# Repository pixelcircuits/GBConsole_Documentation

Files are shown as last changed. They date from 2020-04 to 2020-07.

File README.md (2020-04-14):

# GameBoy Console
The GameBoy Console is an emulator that plays physical GameBoy, GameBoy Color and GameBoy Advance cartridges on your TV! The goal of this project is to provide an inexpensive solution for revisiting beloved GameBoy games on the big screen and help preserve cartridge save data.

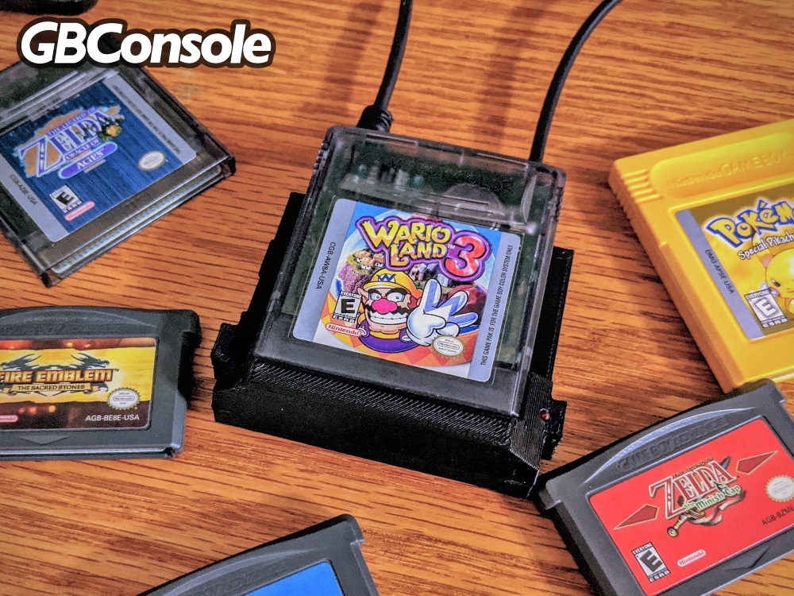
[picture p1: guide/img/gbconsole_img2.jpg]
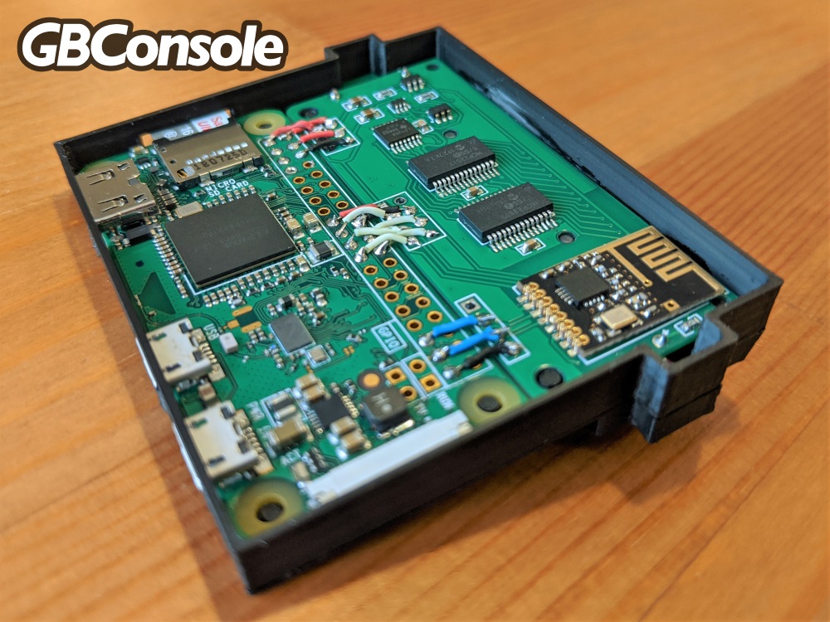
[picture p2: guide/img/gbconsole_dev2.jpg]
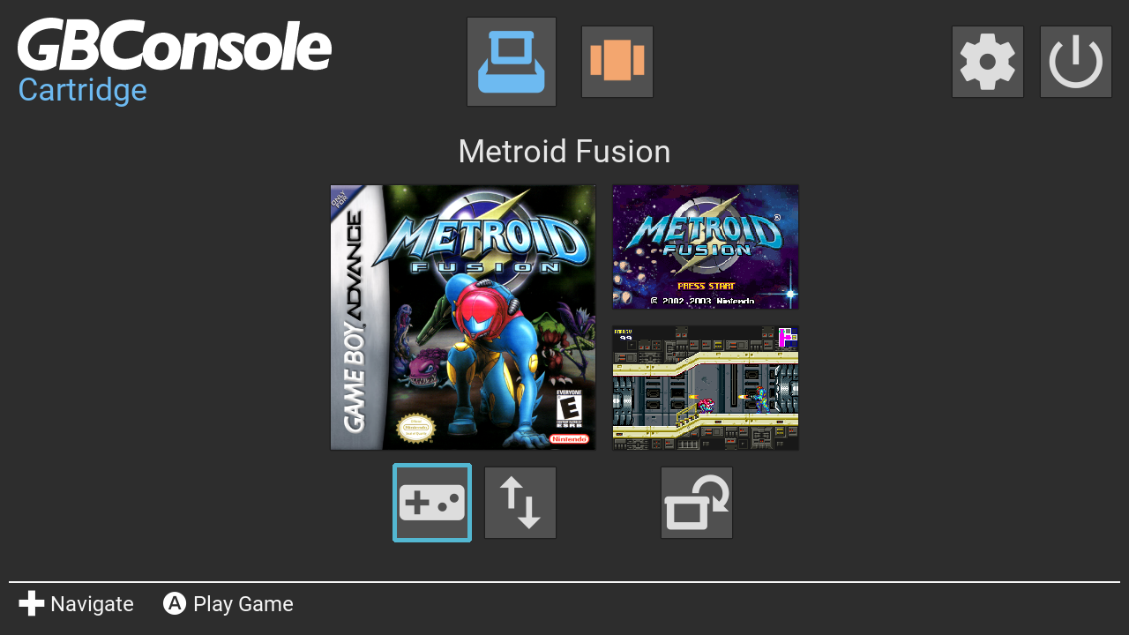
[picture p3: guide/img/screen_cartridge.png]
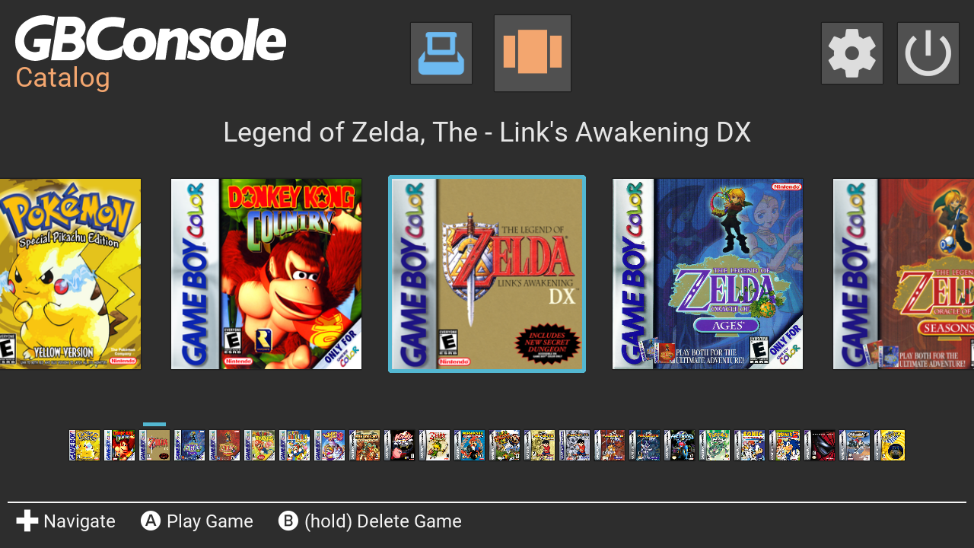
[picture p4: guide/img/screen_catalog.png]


## Documentation
Refer to the following links for more info on the assembly and features of the GameBoy Console.
* [Case Assembly](/case)
* [PCB Assembly](/pcb)
* [Software Setup](https://github.com/pixelcircuits/GBConsole)
* [User Guide](/guide)

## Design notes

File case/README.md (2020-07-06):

# GameBoy Console Case
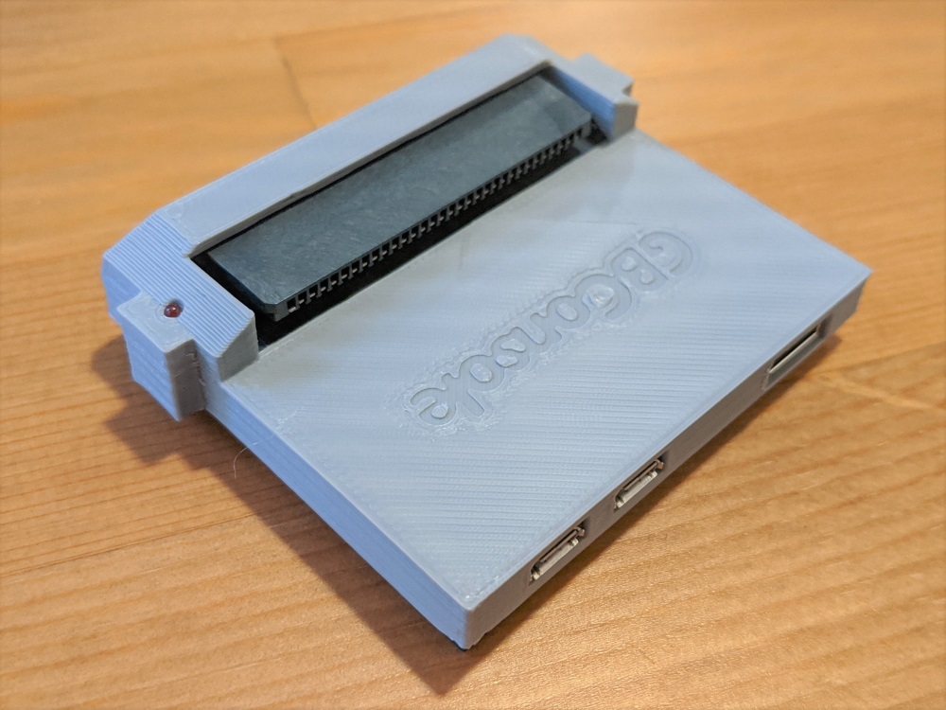
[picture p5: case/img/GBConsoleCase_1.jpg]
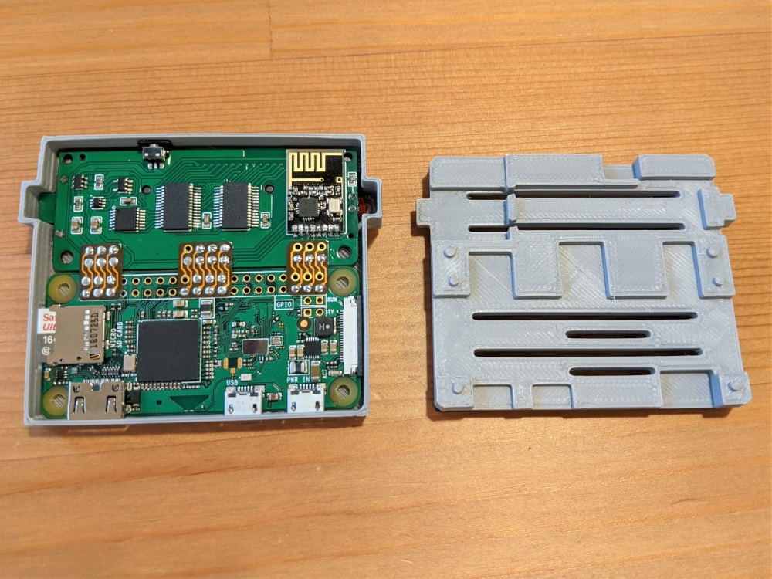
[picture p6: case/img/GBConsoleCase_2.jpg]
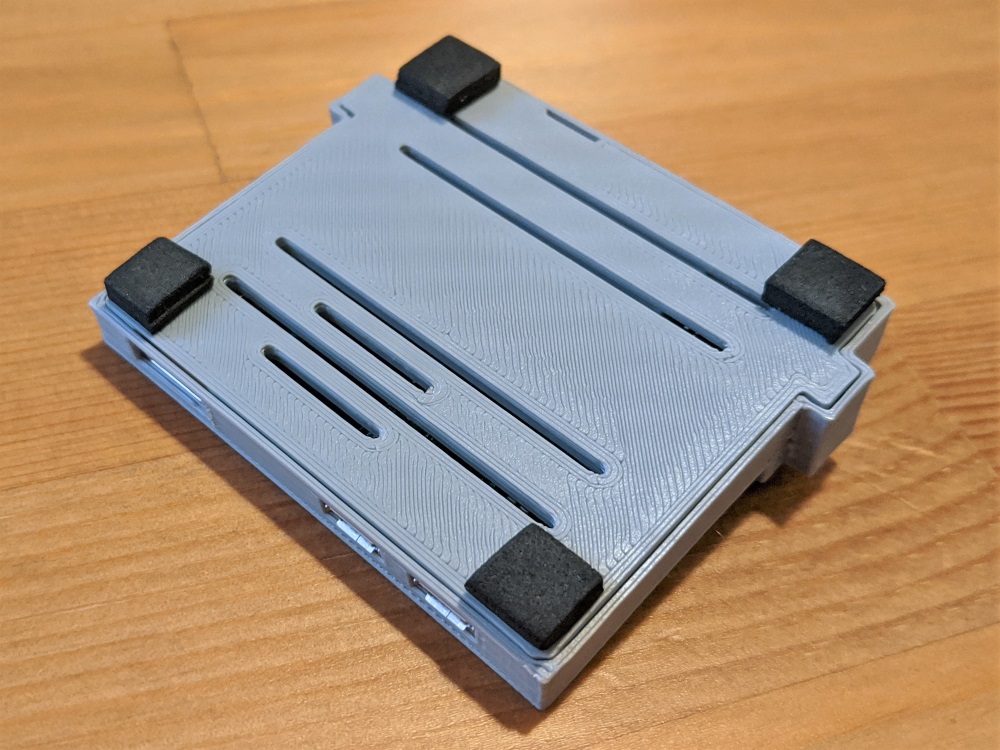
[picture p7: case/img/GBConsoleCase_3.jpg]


The GameBoy Console was designed to fit nicely into a 3D printed case. The case consists of two main parts (body and bottom).

## Case Body
The case body is split into two parts (top and bottom). These two pieces should friction fit together with all the circuitry placed inside. Rubber feet should be applied to the bottom four corners to elevate the case and allow airflow to carry away heat.
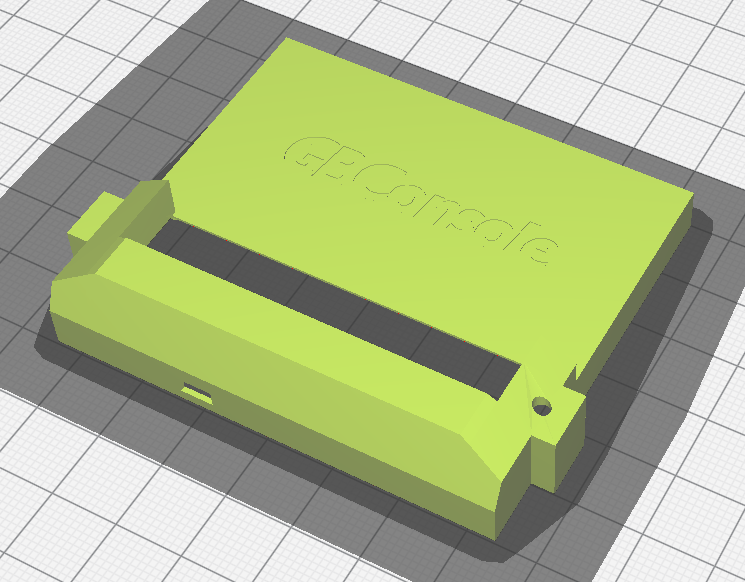
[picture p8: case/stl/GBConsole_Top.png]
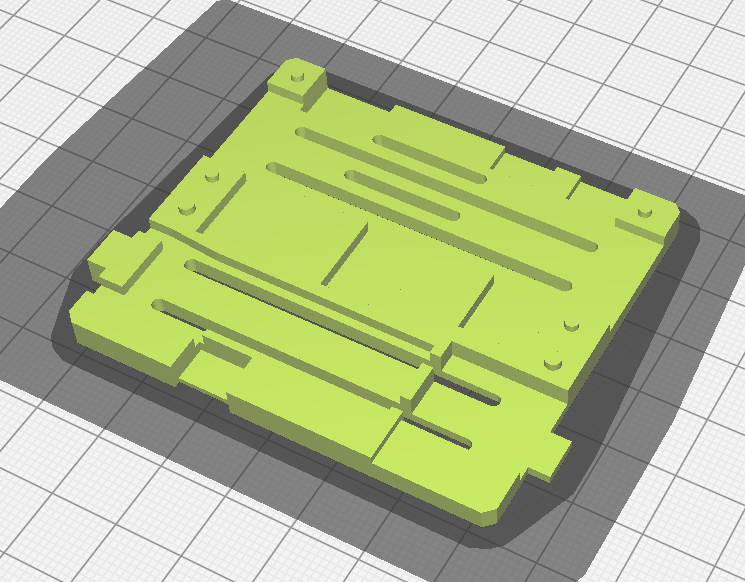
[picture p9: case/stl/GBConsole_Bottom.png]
|  |  |
| --- | --- |
| [GBConsole_Top.stl](stl/GBConsole_Top.stl) | [GBConsole_Bottom.stl](stl/GBConsole_Bottom.stl) |

## Case Button
Additionally, there is a small button cap to help trigger the tact switch through the front side of the case.
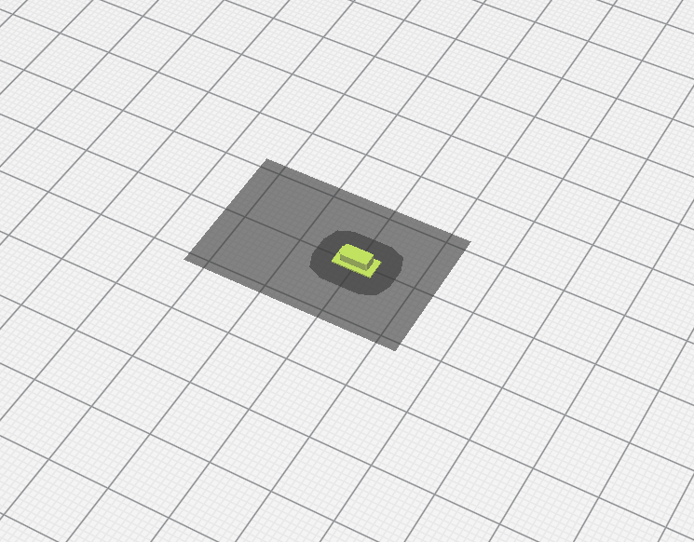
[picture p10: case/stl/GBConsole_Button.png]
|  |
| --- |
| [GBConsole_Button.stl](stl/GBConsole_Button.stl) |

## Assembly
To assemble the GameBoy Console case, fit the fully soldered circuitry into the top of the case by placing in the Raspberry Pi side first (make sure to remove the SD card). The case bottom should then fit and lock into place from the print lines. Refer to the photos if you need additional help.

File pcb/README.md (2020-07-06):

# GameBoy Console PCB
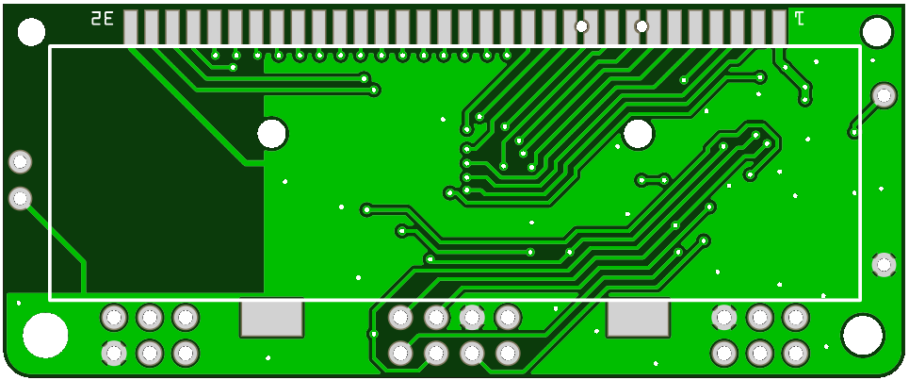
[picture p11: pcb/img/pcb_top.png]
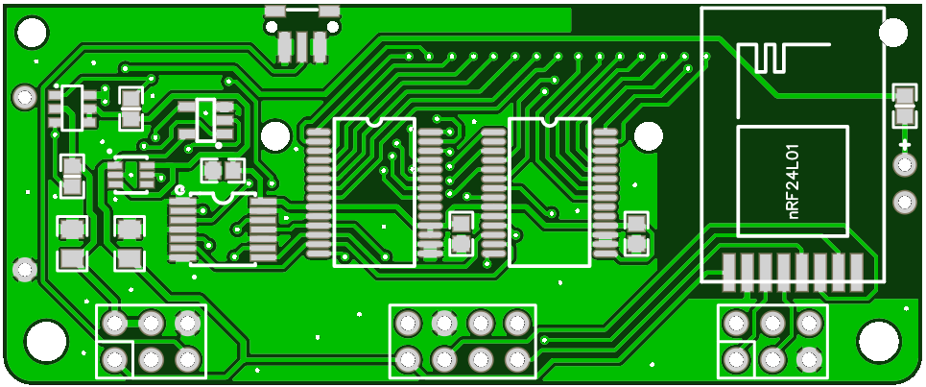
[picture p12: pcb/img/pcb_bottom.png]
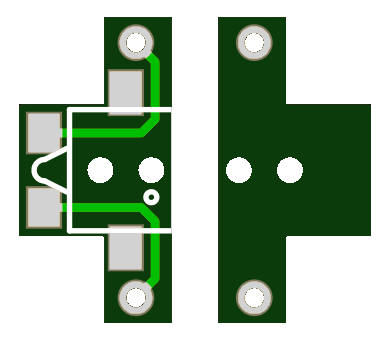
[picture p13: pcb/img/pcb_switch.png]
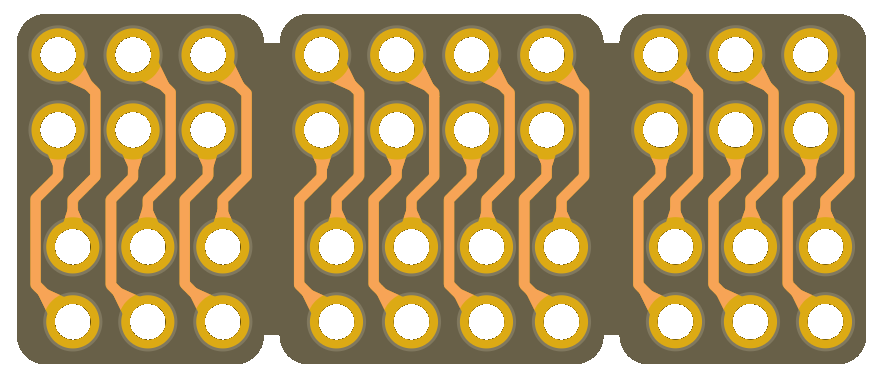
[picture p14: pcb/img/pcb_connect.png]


The GameBoy Console utilizes a custom PCB connected to the GPIO of a Raspberry Pi to help interface with GameBoy, GameBoy Color and GameBoy Advance cartridges. The PCB also includes space for an RF module to help connect to different wireless controllers. Along with the main board, there is a riser PCB for the detector swith and a flex PCB to help easy wire the main board to a Raspberry Pi.

## Schematic Overview
The circuitry consists primarily of two GPIO expander chips (MCP23S17T) to both reduce GPIO requirements and allow for easier logic shifting from 3.3 to 5 volts. There are two ICs (SN74LV1T125 and SN74LVC125A) which buffer the data signals coming from and to the Raspberry Pi. There are two additional ICs (LM66100 and DMP2240UDM) which help to switch the logic level and control power to the connected cartridge.
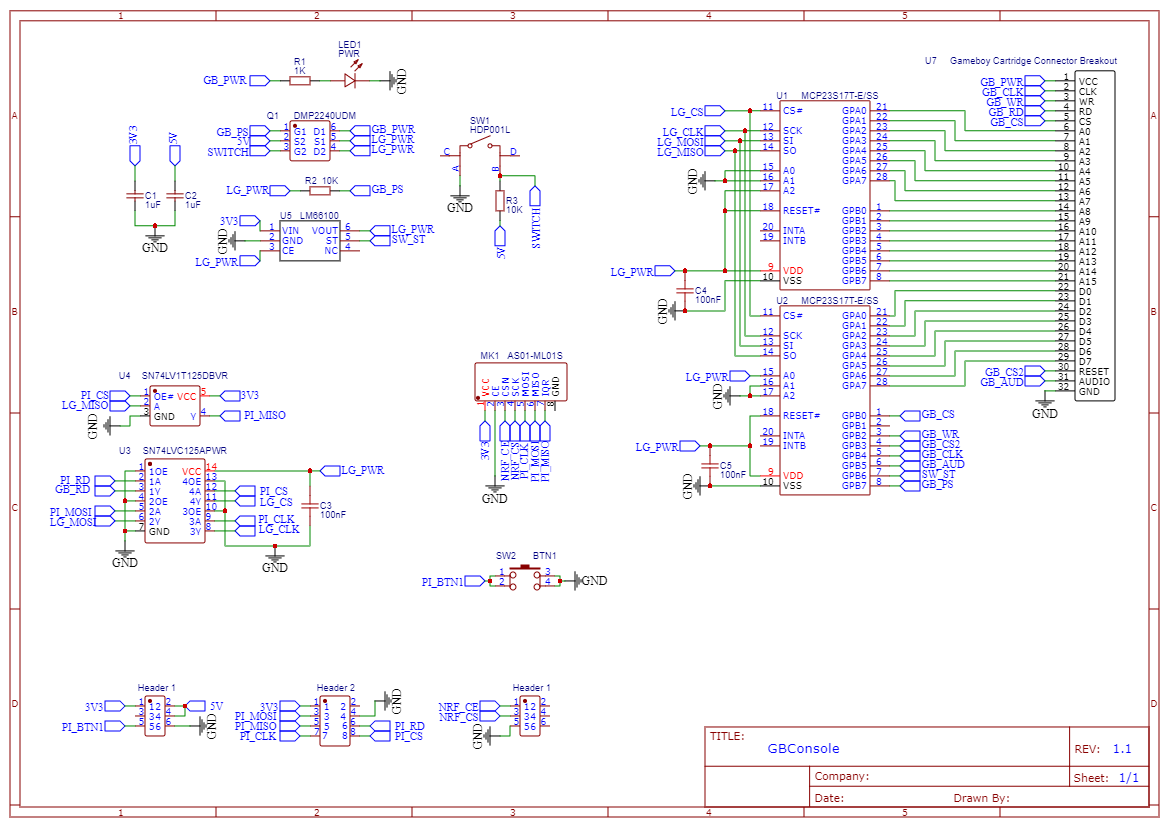
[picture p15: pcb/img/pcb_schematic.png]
Schematic


## Assembly
The gerber files for the main PCB (~1.4mm thickness) can be found [here](gerber/pcb_gerber.zip) and the gerber files for the detector switch PCB (~1mm thickness) can be found [here](gerber/pcb_switch_gerber.zip). Note that the detector switch is first soldered to its own PCB and then soldered to the main PCB. Additionally, a flex PCB for easier wiring can be found [here](gerber/pcb_connect_gerber.zip). Refer to the following diagram for how to assemble the PCB. 
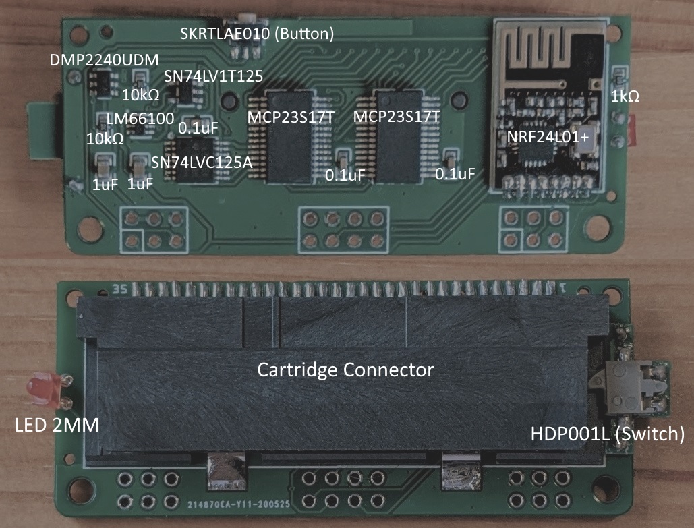
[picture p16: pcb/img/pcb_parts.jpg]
Assembly


## Parts
| Part | Footprint | Qty | Link |
| --- | --- | --- | --- |
| MCP23S17T | SSOP-28 | 2 | [mouser](https://www.mouser.com/ProductDetail/579-MCP23S17T-E-SS) |
| SN74LV1T125 | SOT-23-5 | 1 | [mouser](https://www.mouser.com/ProductDetail/595-74LV1T125DBVRG4) |
| SN74LVC125A | TSSOP-14 | 1 | [mouser](https://www.mouser.com/ProductDetail/595-SN74LVC125APWR) |
| LM66100 | SC70-6 | 1 | [mouser](https://www.mouser.com/ProductDetail/595-LM66100DCKT) |
| DMP2240UDM | SOT-26-6 | 1 | [mouser](https://www.mouser.com/ProductDetail/621-DMP2240UDM-7) |
| HDP001L (Switch) | SMT | 1 | [mouser](https://www.mouser.com/ProductDetail/611-HDP001L) |
| SKRTLAE010 (Button) | SMT | 1 | [mouser](https://www.mouser.com/ProductDetail/ALPS/SKRTLAE010?qs=4nKZKRgDHlm3FhoHNgWQ9A%3D%3D) |
| LED 2MM | Through Hole | 1 | [ebay](https://www.ebay.com/itm/1-8mm-2mm-3mm-5mm-8mm-10mm-LED-Diodes-Diffused-White-Red-Blue-Lights-Lamp-Blub/123839145932) |
| GBA Cartridge Connector | SMT | 1 | [ebay](https://www.ebay.com/itm/For-Nintendo-DS-NDS-GBA-Game-Cartridge-Card-Reader-Slot-Repair-Part/323815654861) |
| NRF24L01+ | SMT | 1 | [ebay](https://www.ebay.com/itm/NRF24L01-SMD-Wireless-Transceiver-Module-1-9-3-6V-1-27-2-4-GHz-MM-Mini-Board/233433878914) |
| CAP 0.1uF | 0603 | 3 | |
| CAP 1uF | 0805 | 2 | |
| RES 10k | 0603 | 2 | |
| RES 1k | 0603 | 1 | |

## Wiring to Raspberry Pi
The PCB is designed to sit off to the side of the Raspberry Pi GPIO with jumper wires soldered to the corresponding pads. The provided flex PCB can be used to avoid having to cut and strip tiny wires. Note that it is a good idea to seat the boards in the case and tape them together before soldering so the spacing is correct.
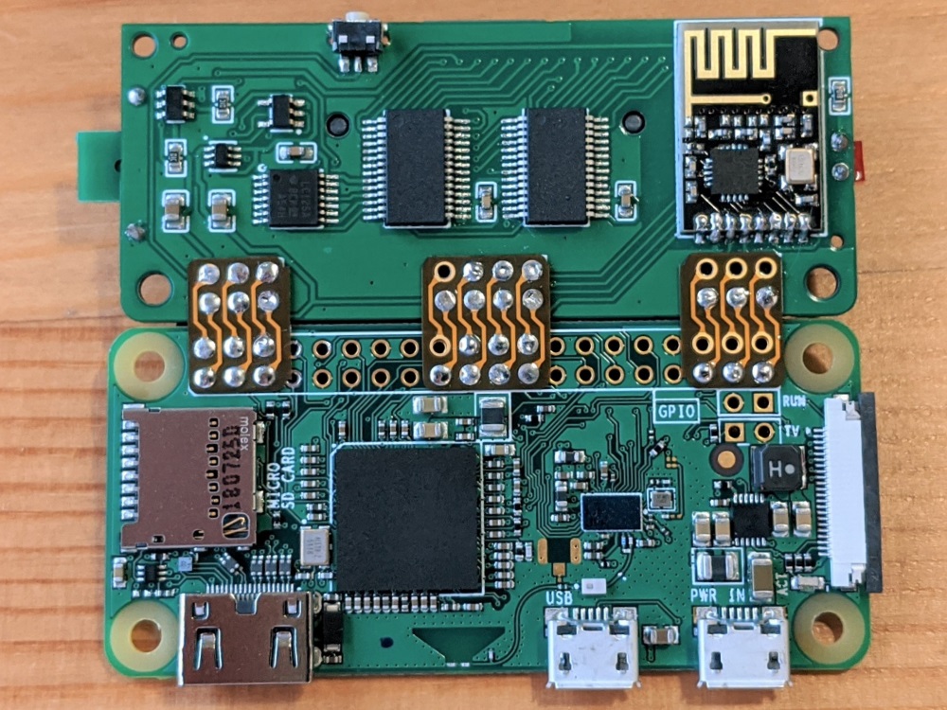
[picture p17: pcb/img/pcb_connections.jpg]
Wiring to Raspberry Pi

Not all the connections are used at this time so some of them can be skipped (the ones not soldered in the diagram) but it doesn't hurt to solder them all. Also remember to seat the boards in the case and tape them together before soldering to make things easier.

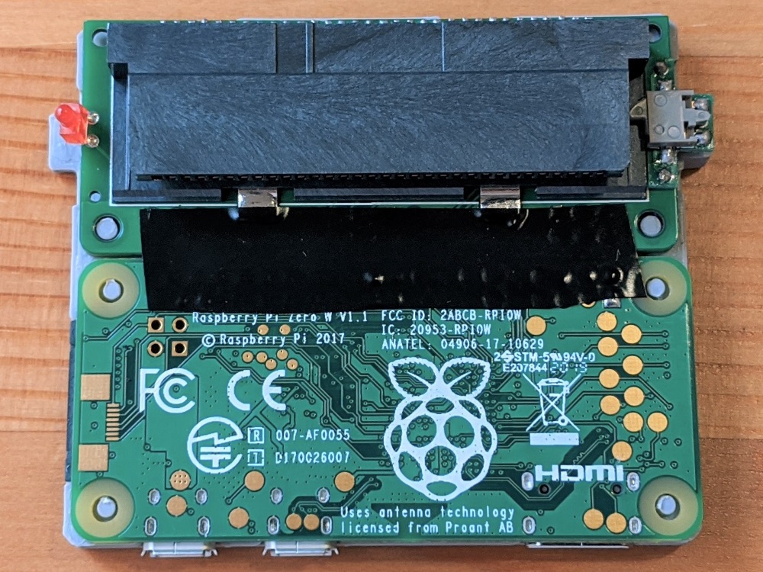
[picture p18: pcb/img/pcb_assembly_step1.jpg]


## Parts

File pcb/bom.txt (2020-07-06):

Part	Footprint	Qty	Link
MCP23S17T	SSOP-28	2	https://www.mouser.com/ProductDetail/579-MCP23S17T-E-SS
SN74LV1T125	SOT-23-5	1	https://www.mouser.com/ProductDetail/595-74LV1T125DBVRG4
SN74LVC125A	TSSOP-14	1	https://www.mouser.com/ProductDetail/595-SN74LVC125APWR
LM66100	SC70-6	1	https://www.mouser.com/ProductDetail/595-LM66100DCKT
DMP2240UDM	SOT-26-6	1	https://www.mouser.com/ProductDetail/621-DMP2240UDM-7
HDP001L (Switch)	SMT	1	https://www.mouser.com/ProductDetail/611-HDP001L
SKRTLAE010 (Button)	SMT	1	https://www.mouser.com/ProductDetail/ALPS/SKRTLAE010?qs=4nKZKRgDHlm3FhoHNgWQ9A%3D%3D
LED 2MM	Through Hole	1	https://www.ebay.com/itm/1-8mm-2mm-3mm-5mm-8mm-10mm-LED-Diodes-Diffused-White-Red-Blue-Lights-Lamp-Blub/123839145932
GBA Cartridge Connector	SMT	1	https://www.ebay.com/itm/For-Nintendo-DS-NDS-GBA-Game-Cartridge-Card-Reader-Slot-Repair-Part/323815654861
NRF24L01+	SMT	1	https://www.ebay.com/itm/NRF24L01-SMD-Wireless-Transceiver-Module-1-9-3-6V-1-27-2-4-GHz-MM-Mini-Board/233433878914
CAP 0.1uF	0603	3	
CAP 1uF	0805	2	
RES 10k	0603	2	
RES 1k	0603	1

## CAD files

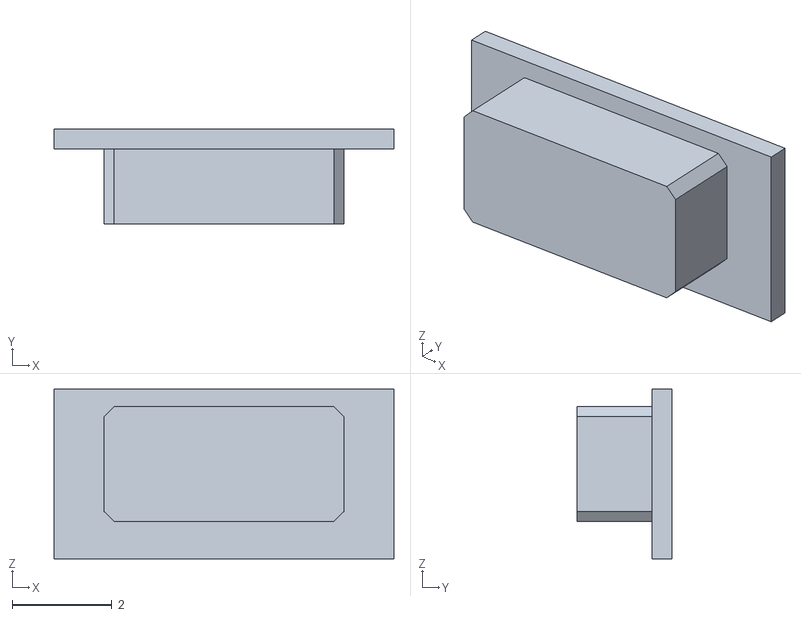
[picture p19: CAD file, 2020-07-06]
case/stl/GBConsole_Button.stl
6.80 x 1.90 x 3.40

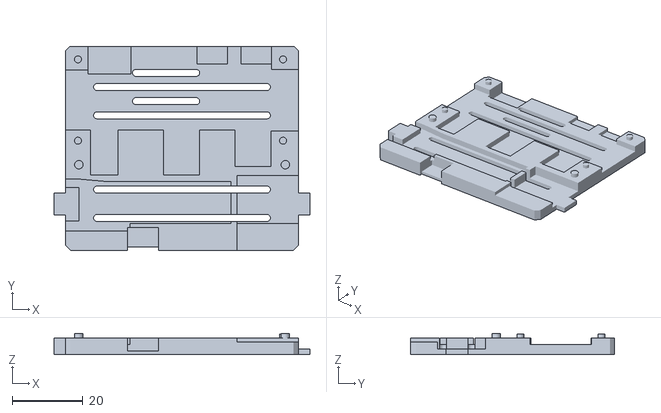
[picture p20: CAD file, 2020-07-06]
case/stl/GBConsole_Bottom.stl
72.4 x 57.6 x 5.95

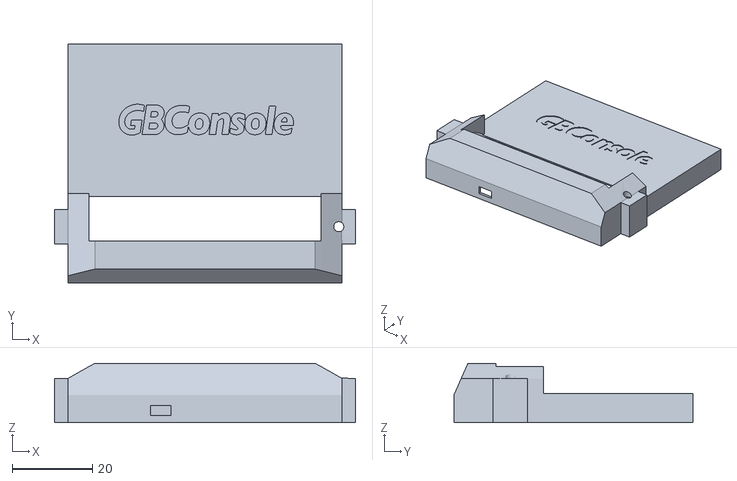
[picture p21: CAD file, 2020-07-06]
case/stl/GBConsole_Top.stl
74.8 x 59.5 x 14.7

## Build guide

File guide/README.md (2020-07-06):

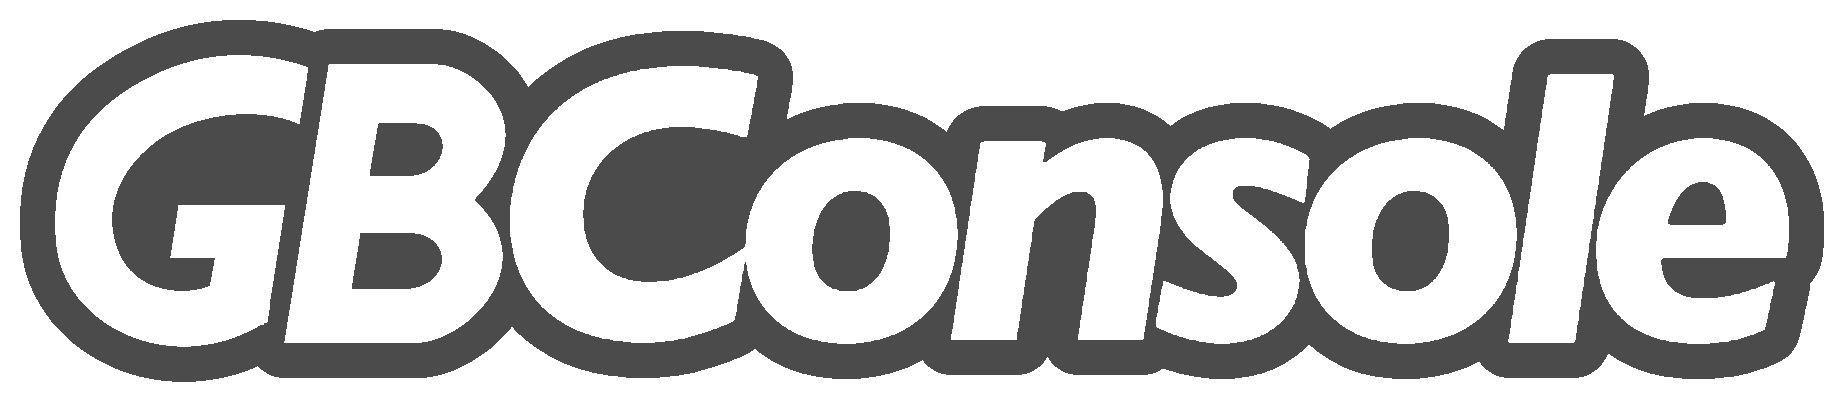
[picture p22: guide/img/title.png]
GBConsole

# User Guide

1. [Overview](#Overview)
   * [Connecting Cartridges](#Overview_ConnectingCartridges)
   * [Hardware Layout](#Overview_HardwareLayout)
   * [Power On/Off](#Overview_PowerOnOff)
   * [BIOS Files](#Overview_BIOSFiles)
2. [Controls](#Controls)
   * [Keyboard](#Controls_Keyboard)
   * [8bitdo](#Controls_8bitdo)
   * [Wireless Game Receiver](#Controls_WirelessGameReceiver)
3. [Cartridge](#Cartridge)
   * [Load](#Cartridge_Load)
   * [Sync](#Cartridge_Sync)
   * [Play](#Cartridge_Play)
4. [Catalog](#Catalog)
   * [Browse](#Catalog_Browse)
   * [Play](#Catalog_Play)
   * [Delete](#Catalog_Delete)
5. [Settings](#Settings)
   * [General](#Settings_General)
   * [USB Backup/Restore](#Settings_USBBackupRestore)
   * [Bluetooth](#Settings_Bluetooth)

## 1. Overview 
The GameBoy Console is an emulator that plays physical GameBoy, GameBoy Color and GameBoy Advance cartridges on your TV! The goal of this project is to provide an inexpensive solution for revisiting beloved GameBoy games on the big screen and help preserve cartridge save data. Additionally, the system hardware supports connecting to the [Wireless Gameboy Controller](https://shop.insidegadgets.com/product/wireless-gameboy-controller//) cartridge to enable playing on your TV while using your Gameboy as a controller!

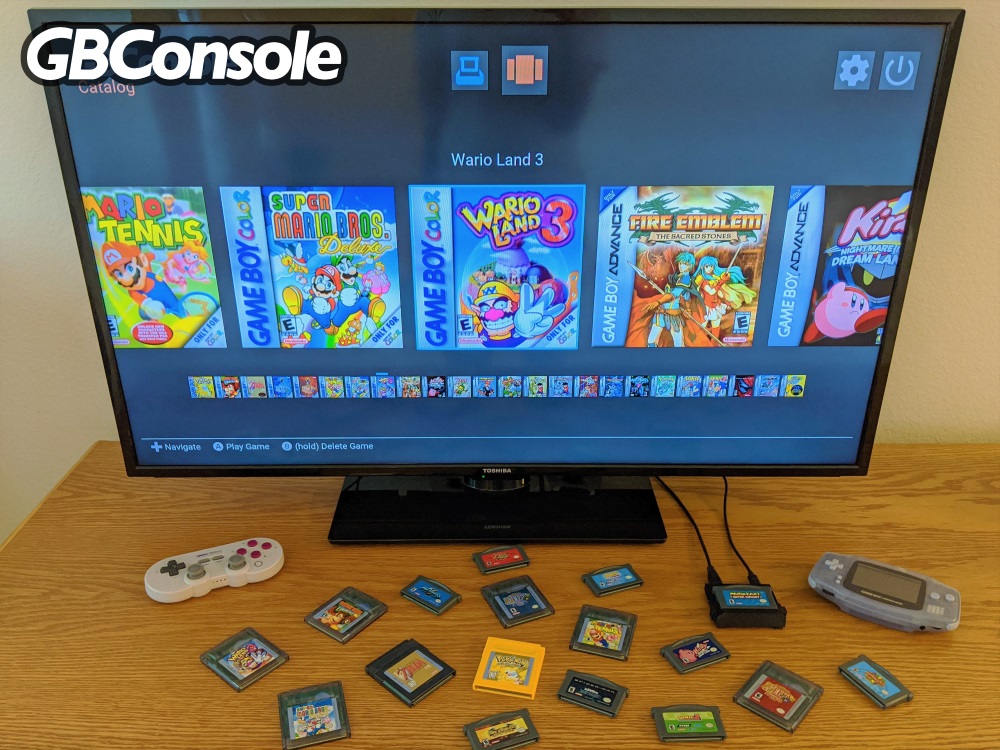
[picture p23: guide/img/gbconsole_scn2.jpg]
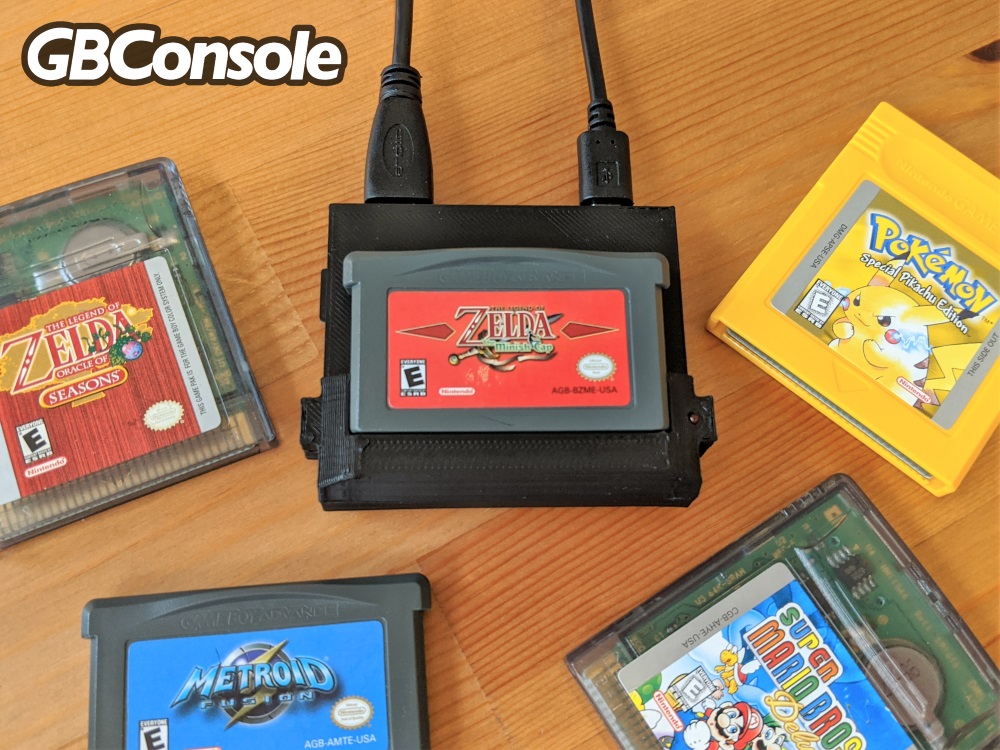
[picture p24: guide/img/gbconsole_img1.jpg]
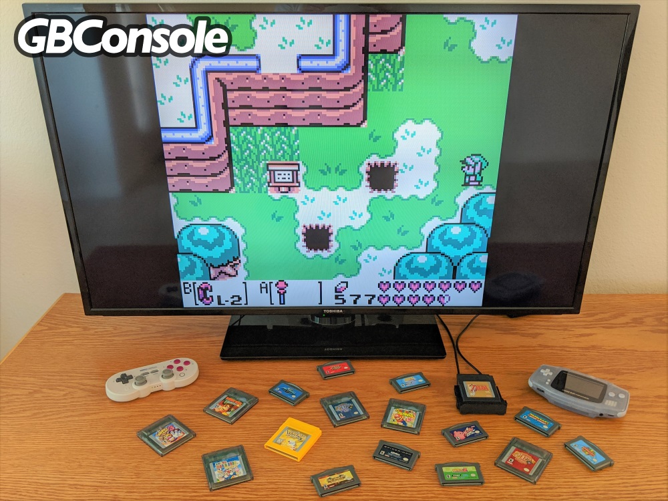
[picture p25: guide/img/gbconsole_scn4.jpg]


### Connecting Cartridges 
The cartridge connector supports GameBoy, GameBoy Color and GameBoy Advance cartridges. Only when the status LED is on is the cartridge receiving power. When the status LED is off, you are free to connect and disconnect cartridges. The system runs on a syncing concept where cartridges are cloned onto the system and put into a virtual catalog. The cartridge then no longer needs to be connected to play and only needs to be connected to transfer updated save data back to the cartridge. Similarly, if cartridge save data has been updated, running the sync process allows for the system save data to be updated to the cartridge state.

### Hardware Layout 
The GameBoy Console is powered by a Raspberry Pi zero. A connected SD card contains the operating system and stores all data of the backed up cartridges for the catalog. Refer to the following diagram for locating the Status LED, Power/Bluetooth Button, Micro USB power connector, Micro USB peripheral port and Mini HDMI port.

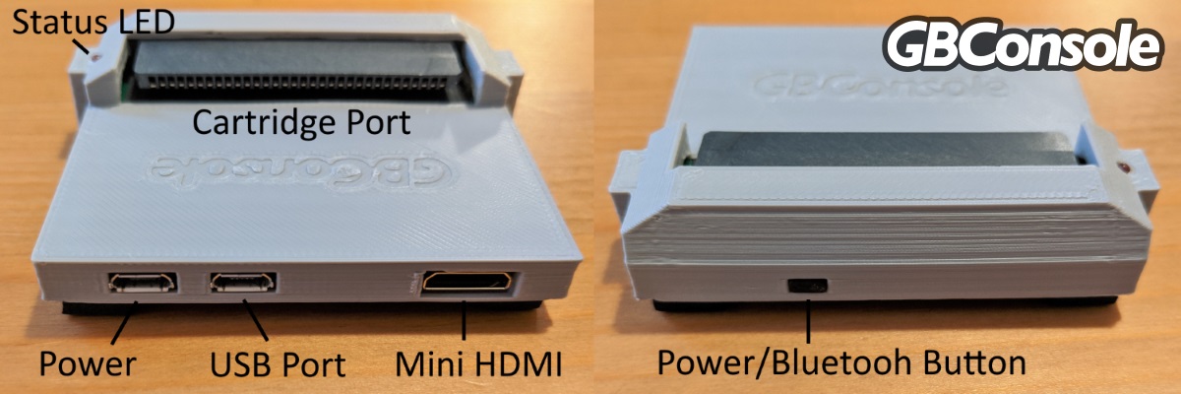
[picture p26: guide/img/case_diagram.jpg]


### Power On/Off 
The GameBoy Console should boot up when the power is first plugged in. To quickly and easily shut down the system, hold down the button on the front of the case. Once shutdown, simply press the front button to have the system boot up again. Additionally, you can manually shutdown from the system menu by selecting the shutdown icon  at the top of the system menu. You will then be prompted to confirm you want to shut down the system. Failing to shutdown the system safely could result in corruption of the SD card and potential loss of data.

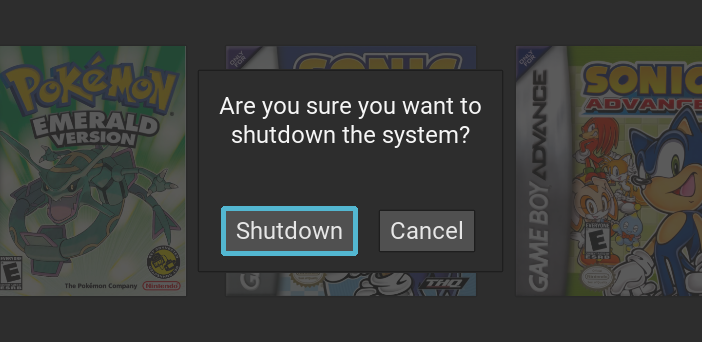
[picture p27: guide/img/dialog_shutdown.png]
Shutdown Dialog


### BIOS Files 
Currently, fast GameBoy Advance emulation requires that you provide a GBA bios file. This file should be named "gba_bios.bin" and placed at the root of a connected USB drive or on the SD card boot partition. On boot, the GameBoy Console will look for this file and copy it to the system if it is found. Once copied, the file no longer needs to be on the USB drive or SD card boot partition.

## 2. Controls 
The GameBoy Console supports the following controller options.

### Keyboard 
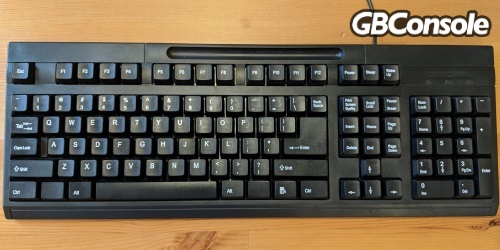
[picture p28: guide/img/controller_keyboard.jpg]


The most straight forward controller option is a standard keyboard connected to the USB port. Refer to the following chart for the keyboard key mapping.

| Up | Down | Left | Right | Select | Start | A | B | L | R |
|:--- |:--- |:--- |:--- |:--- |:----- |:----- |:----- |:----- |:----- |
| Up Arrow | Down Arrow | Left Arrow | Right Arrow | Right Shift | Enter | X Key | Z Key | Q Key | W Key |

*Hotkeys*

| Exit | Save Slot Increase | Save Slot Decrease | Save State | Load State | Fast Forward | Pause |
|:---- |:--- |:--- |:--- |:--- |:--- |:----- |
| Esc  | F7 | F6 | F2 | F4 | Space | P Key | 

### 8BitDo 
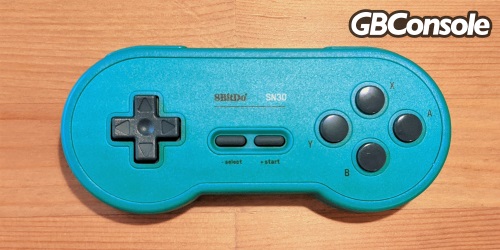
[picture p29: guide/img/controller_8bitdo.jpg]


Currently, the only controllers supported are the [SN30](https://www.8bitdo.com/sn30-gp/) and [SN30 Pro](https://www.8bitdo.com/sn30-pro-g-classic-or-sn30-pro-sn/) from 8BitDo. These can be plugged into the USB port or optionally connected via bluetooth (see [Settings](#Settings_Bluetooth)). Holding the X key enables the use of the following hotkeys.

| Exit | Save Slot Increase | Save Slot Decrease | Save State | Load State | Fast Forward | Pause |
|:--- |:--- |:--- |:--- |:--- |:--- |:--- |
| X+Start | X+Right | X+Left | X+Up | X+Down | X+A | X+Select |

### Wireless Gameboy Controller 
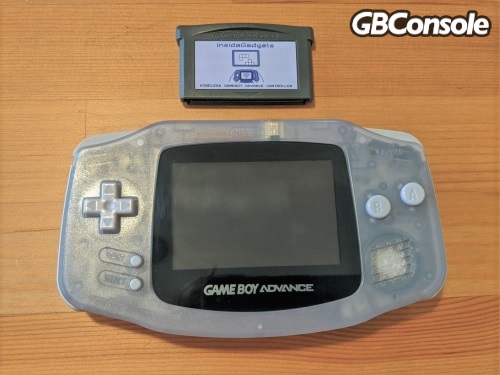
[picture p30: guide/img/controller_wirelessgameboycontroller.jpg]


The GameBoy Console also supports connecting to the [Wireless Gameboy Controller](https://shop.insidegadgets.com/product/wireless-gameboy-controller//) from insideGadgets. Make sure the controller is set to its defaults and it should connect automatically. Hotkeys can only be used from a different connected controller or keyboard. To exit a game with this controller, simply hold down A+B+L+R+Start+Select.

## 3. Cartridge 
The cartridge section of the menu can be opened by selecting the blue cartridge icon  at the top of the system menu. This is the main section for performing actions with physically connected cartridges *(note that you are free to connect and disconnect cartridges from the system as long as the status LED is not on)*. From here you can perform the following operations.

Cartridge Screen

### Load 
When this section is first opened, the system will attempt to identify the connected cartridge. If recognized, the system will provide box art and screen captures from the game. The refresh icon  can be selected at any time to re check the connected cartridge. Once loaded, additional actions will be available to choose for the cartridge.

### Sync 
The main action related to cartridges is the sync option. Select the sync icon  to match the system data to the physical cartridge. If this is a new cartridge, the game data and save data will both be backed up to the system. If this is a cartridge that the system has already backed up, syncing will attempt to copy the system save data state to the cartridge. If the cartridge save data has been updated since the last sync, you will be prompted on whether you want to update the system or update the cartridge.

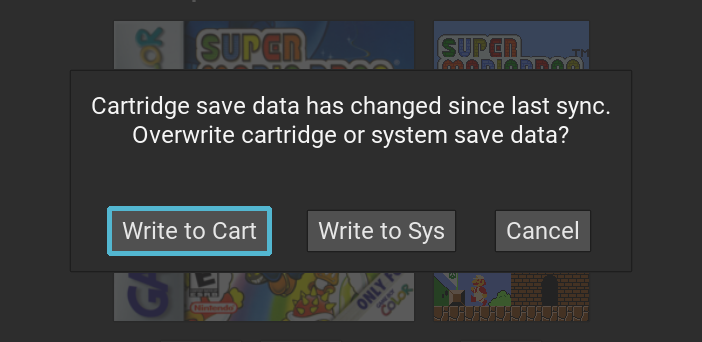
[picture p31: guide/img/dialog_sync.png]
Sync Dialog


### Play 
If the cart has already been backed up into the system, you can select to play the cartridge by selecting the play icon .

## 4. Catalog 
The catalog section of the menu can be opened by selecting the orange catalog icon  at the top of the system menu. This section allows you to browse all backed up cartridges currently on the system.

Catalog Screen

### Browse 
To browse the backed up cartridges on the system simply navigated along the carousel using the left and right buttons. If the catalog is large, you’ll have to navigate through multiple pages *(denoted by arrows on the edge of the carousel)*.

### Play 
Selecting any of the cartridges in the catalog with the A button will begin playing it *(note that the cartridge does not need to be connected in order to play it)*.

### Delete 
To remove a backed up cartridge from the catalog simply navigate to it and then hold down the B button. You will be prompted with a confirmation that you want to remove all data related to this cartridge from the system.

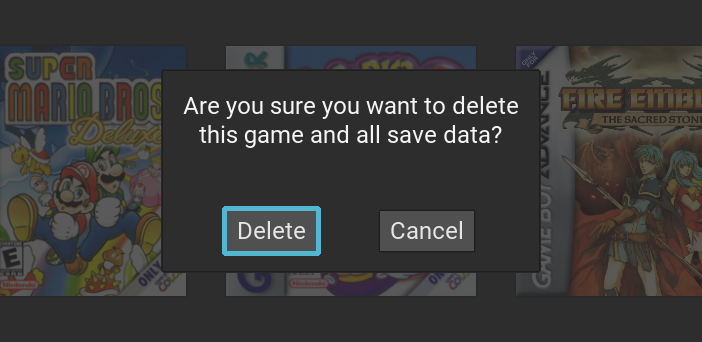
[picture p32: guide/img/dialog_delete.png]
Delete Dialog


## 5. Settings 
The settings section of the menu can be opened by selecting the settings icon  at the top of the system menu. This section allows you to configure the following system attributes.

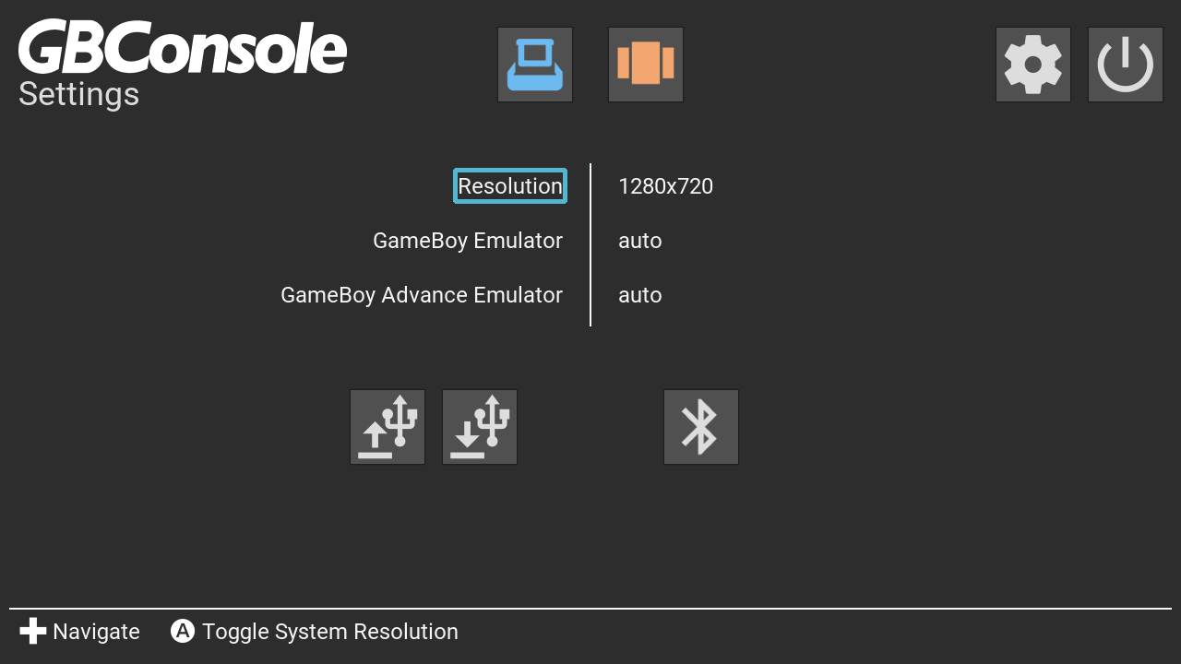
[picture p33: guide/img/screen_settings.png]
Catalog Screen


### General 
There are several general settings that can be tweaked including system resolution and what emulators should be used. Simply highlight the setting you wish to change and press the A button to toggle through options.

### USB Backup/Restore 
All backed up game data can be copied to a USB drive for preservation. Select the USB backup icon  to backup to the connected USB drive or select the restore from USB icon  to restore game data from the USB drive onto the system. All data will show up on the USB drive in a folder called *GBConsole_backup*.

### Bluetooth 
From anywhere in the menu, a bluetooth controller can be quickly connected by pressing the front button (do not hold, or the system will shutdown). Additionally, a bluetooth controller can be connected by selecting the bluetooth icon  from the settings menu. You will be prompted with the option to cancel the process while the system searches for a bluetooth device. Make sure to set the controller into pairing mode during this process and wait a few seconds for it to connect (see [Controls](#Controls)).

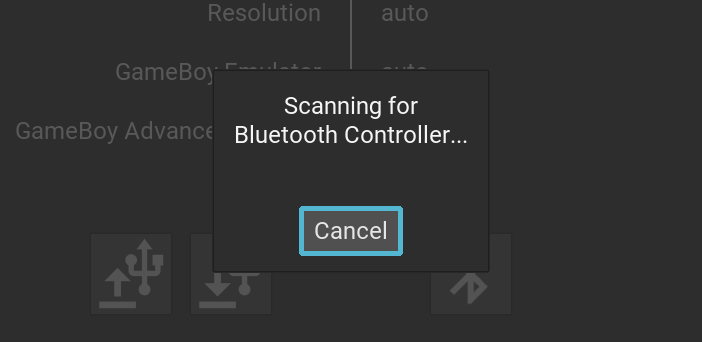
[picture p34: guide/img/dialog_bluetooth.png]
Sync Dialog


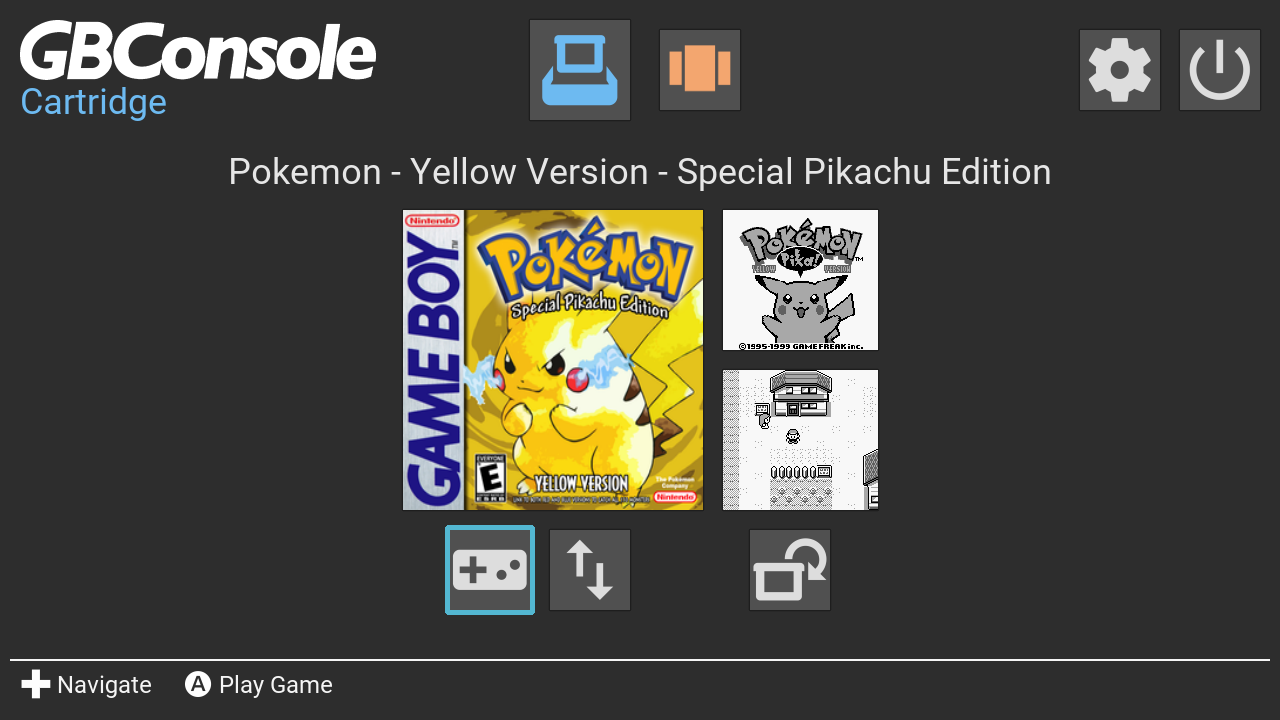
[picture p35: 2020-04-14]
guide/img/screen_cartridge2.png

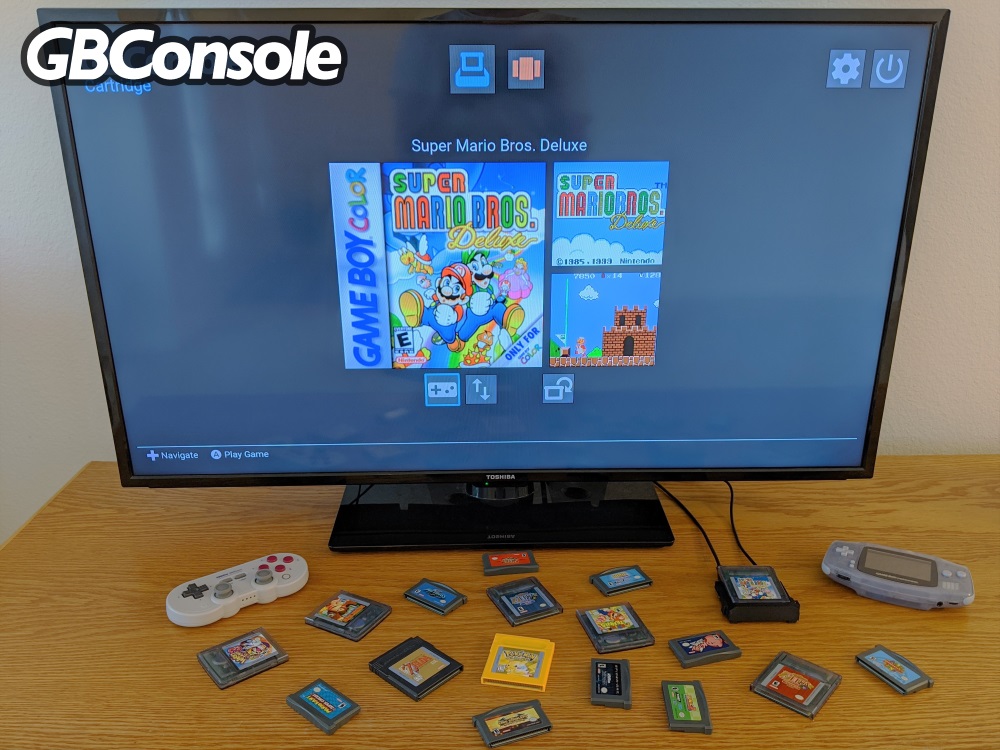
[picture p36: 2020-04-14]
guide/img/gbconsole_scn1.jpg

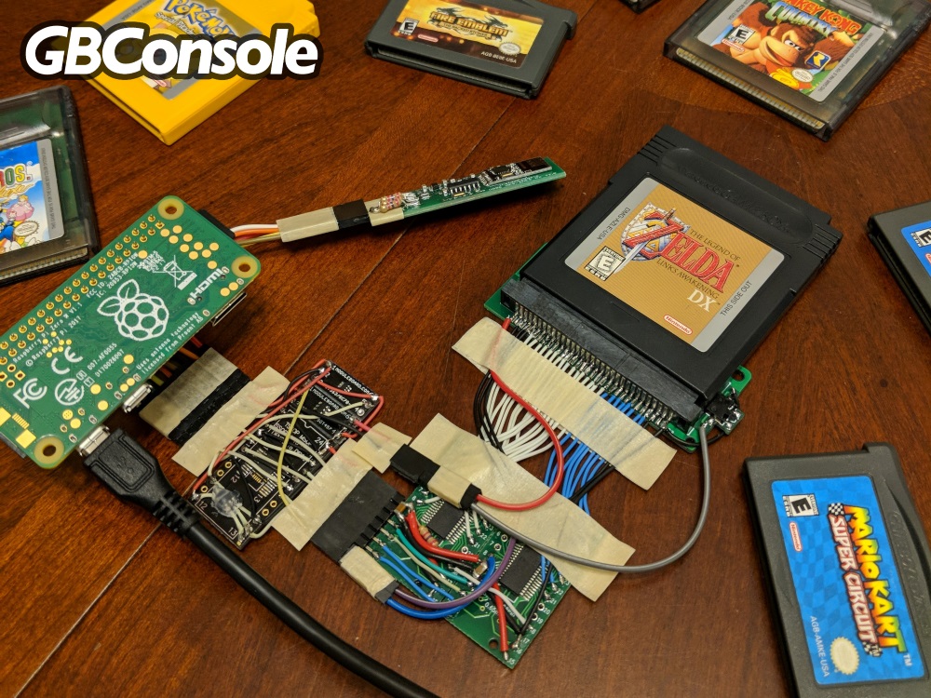
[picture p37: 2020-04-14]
guide/img/gbconsole_dev1.jpg

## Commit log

2020-04-03 Added case and PCB data
    [GBConsole_Body.stl, GBConsole_Bottom.stl, GBConsole_Top.stl]
2020-04-03 Updated case readme
2020-04-04 Added sub-directories to case folder
    [GBConsole_Body.stl, GBConsole_Bottom.stl, GBConsole_Top.stl]
2020-04-04 Updated PCB readme
2020-04-04 Added sub-directories to the PCB section
2020-04-05 Added wiring diagram for PCB
2020-04-15 Updated BOM
2020-07-06 v1.1 case changes
    [GBConsole_Body.stl, GBConsole_Bottom.stl, GBConsole_Button.stl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]
2020-07-06 small schematic change
2020-07-06 Update PCB for v1.1
2020-07-06 Updated case images
2020-07-06 Update case for v1.1
